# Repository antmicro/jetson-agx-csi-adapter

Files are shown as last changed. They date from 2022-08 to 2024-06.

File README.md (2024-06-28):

# Antmicro Jetson AGX CSI Adapter

Copyright (c) 2022-2024 [Antmicro](https://www.antmicro.com)



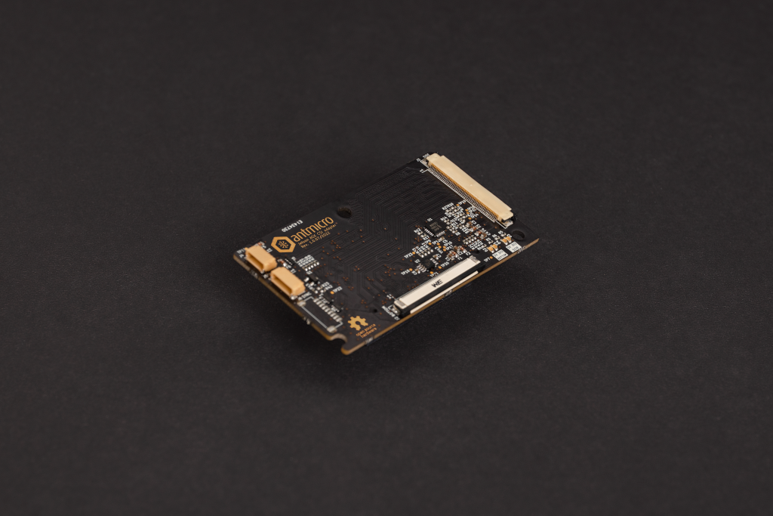
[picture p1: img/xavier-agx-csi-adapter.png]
Adapter Photo


## Overview
This project contains hardware design files for a CSI camera adapter designed to be used with Nvidia Jetson AGX platform devkits (Orin, Xavier).
It separates the camera module interface connector into two 50-pin flat cable connectors, which are compatible with a variety of video accessories developed by Antmicro.
 
## Project structure
The main directory contains KiCad PCB project files, a LICENSE, and a README.
The remaining files are stored in the following directories:

* `img` - contains graphics for this README
* `doc` - contains generated schematics and other documentation
* `assets` - contains visual assets for showcasing this design on [Open Hardware Portal](https://openhardware.antmicro.com)

## Key features
* Nvidia Camera Module Connector compatible with Jetson AGX Orin and Jetson Xavier AGX devkits,
* Two Antmicro CSI Connectors (2x 4-lane MIPI CSI-2 or 4x 4-lane MIPI CSI-2)
* I2C multiplexer for connecting multiple cameras to separate I2C interfaces
* On-board DC-DC converter to power the cameras
* Simple frame synchronization circuitry
* QWIIC connector for external sensors
* Liquid lens connector for I2C-controlled liquid lenses

The camera connectors are electrically compatible with several video accessories created by Antmicro, such as:
 
* [Antmicro - Alvium flexible CSI adapter](https://github.com/antmicro/alvium-flexible-csi-adapter)
* [OV9281 Dual Camera Board](https://github.com/antmicro/ov9281-camera-board)
* [SDI-MIPI bridge](https://github.com/antmicro/sdi-mipi-bridge)
* [HDMI-MIPI bridge](https://github.com/antmicro/hdmi-mipi-bridge)

## License
This project is published under the [Apache-2.0](LICENSE) license.

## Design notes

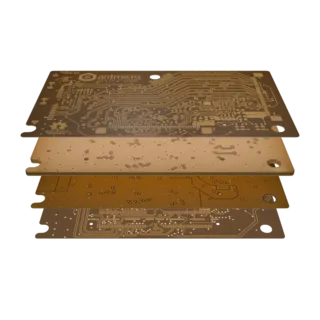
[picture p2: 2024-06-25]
assets/previews/layer1_thumbnail.webp

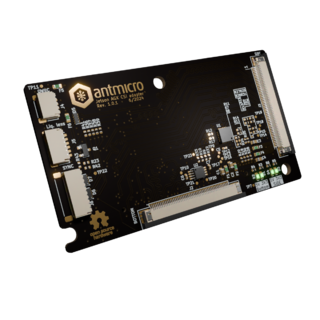
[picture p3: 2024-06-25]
assets/previews/leftT_thumbnail.png

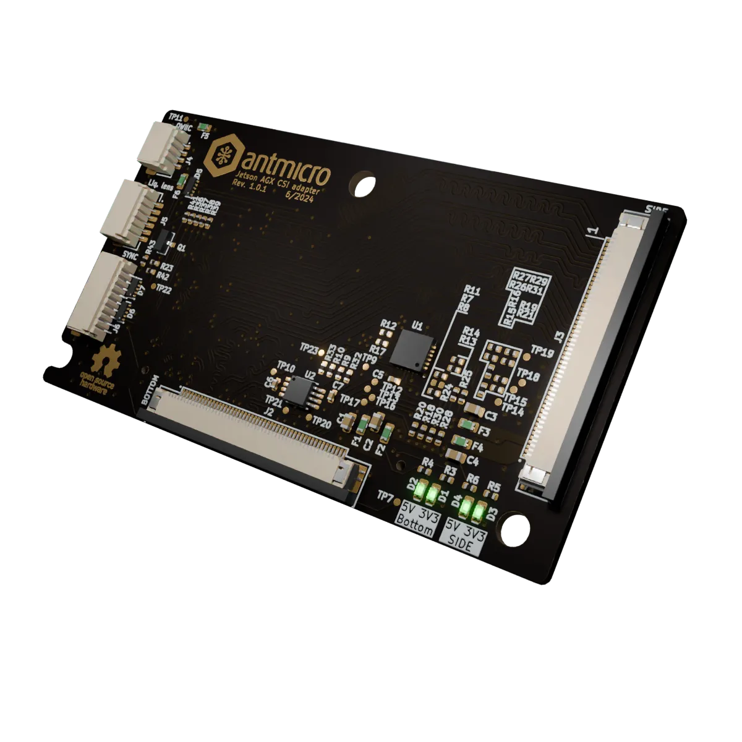
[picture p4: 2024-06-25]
assets/previews/rightT.webp

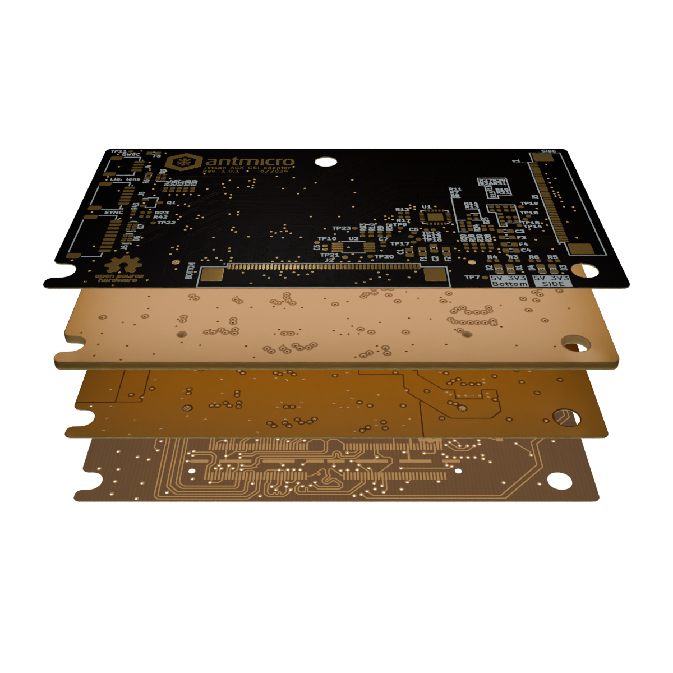
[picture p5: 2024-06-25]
assets/previews/stackup.png

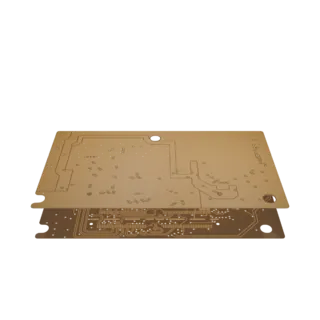
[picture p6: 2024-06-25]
assets/previews/layer3_thumbnail.webp

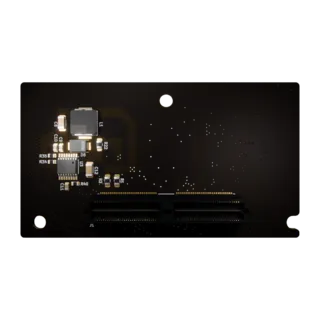
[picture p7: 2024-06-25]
assets/previews/orthoB_thumbnail.webp

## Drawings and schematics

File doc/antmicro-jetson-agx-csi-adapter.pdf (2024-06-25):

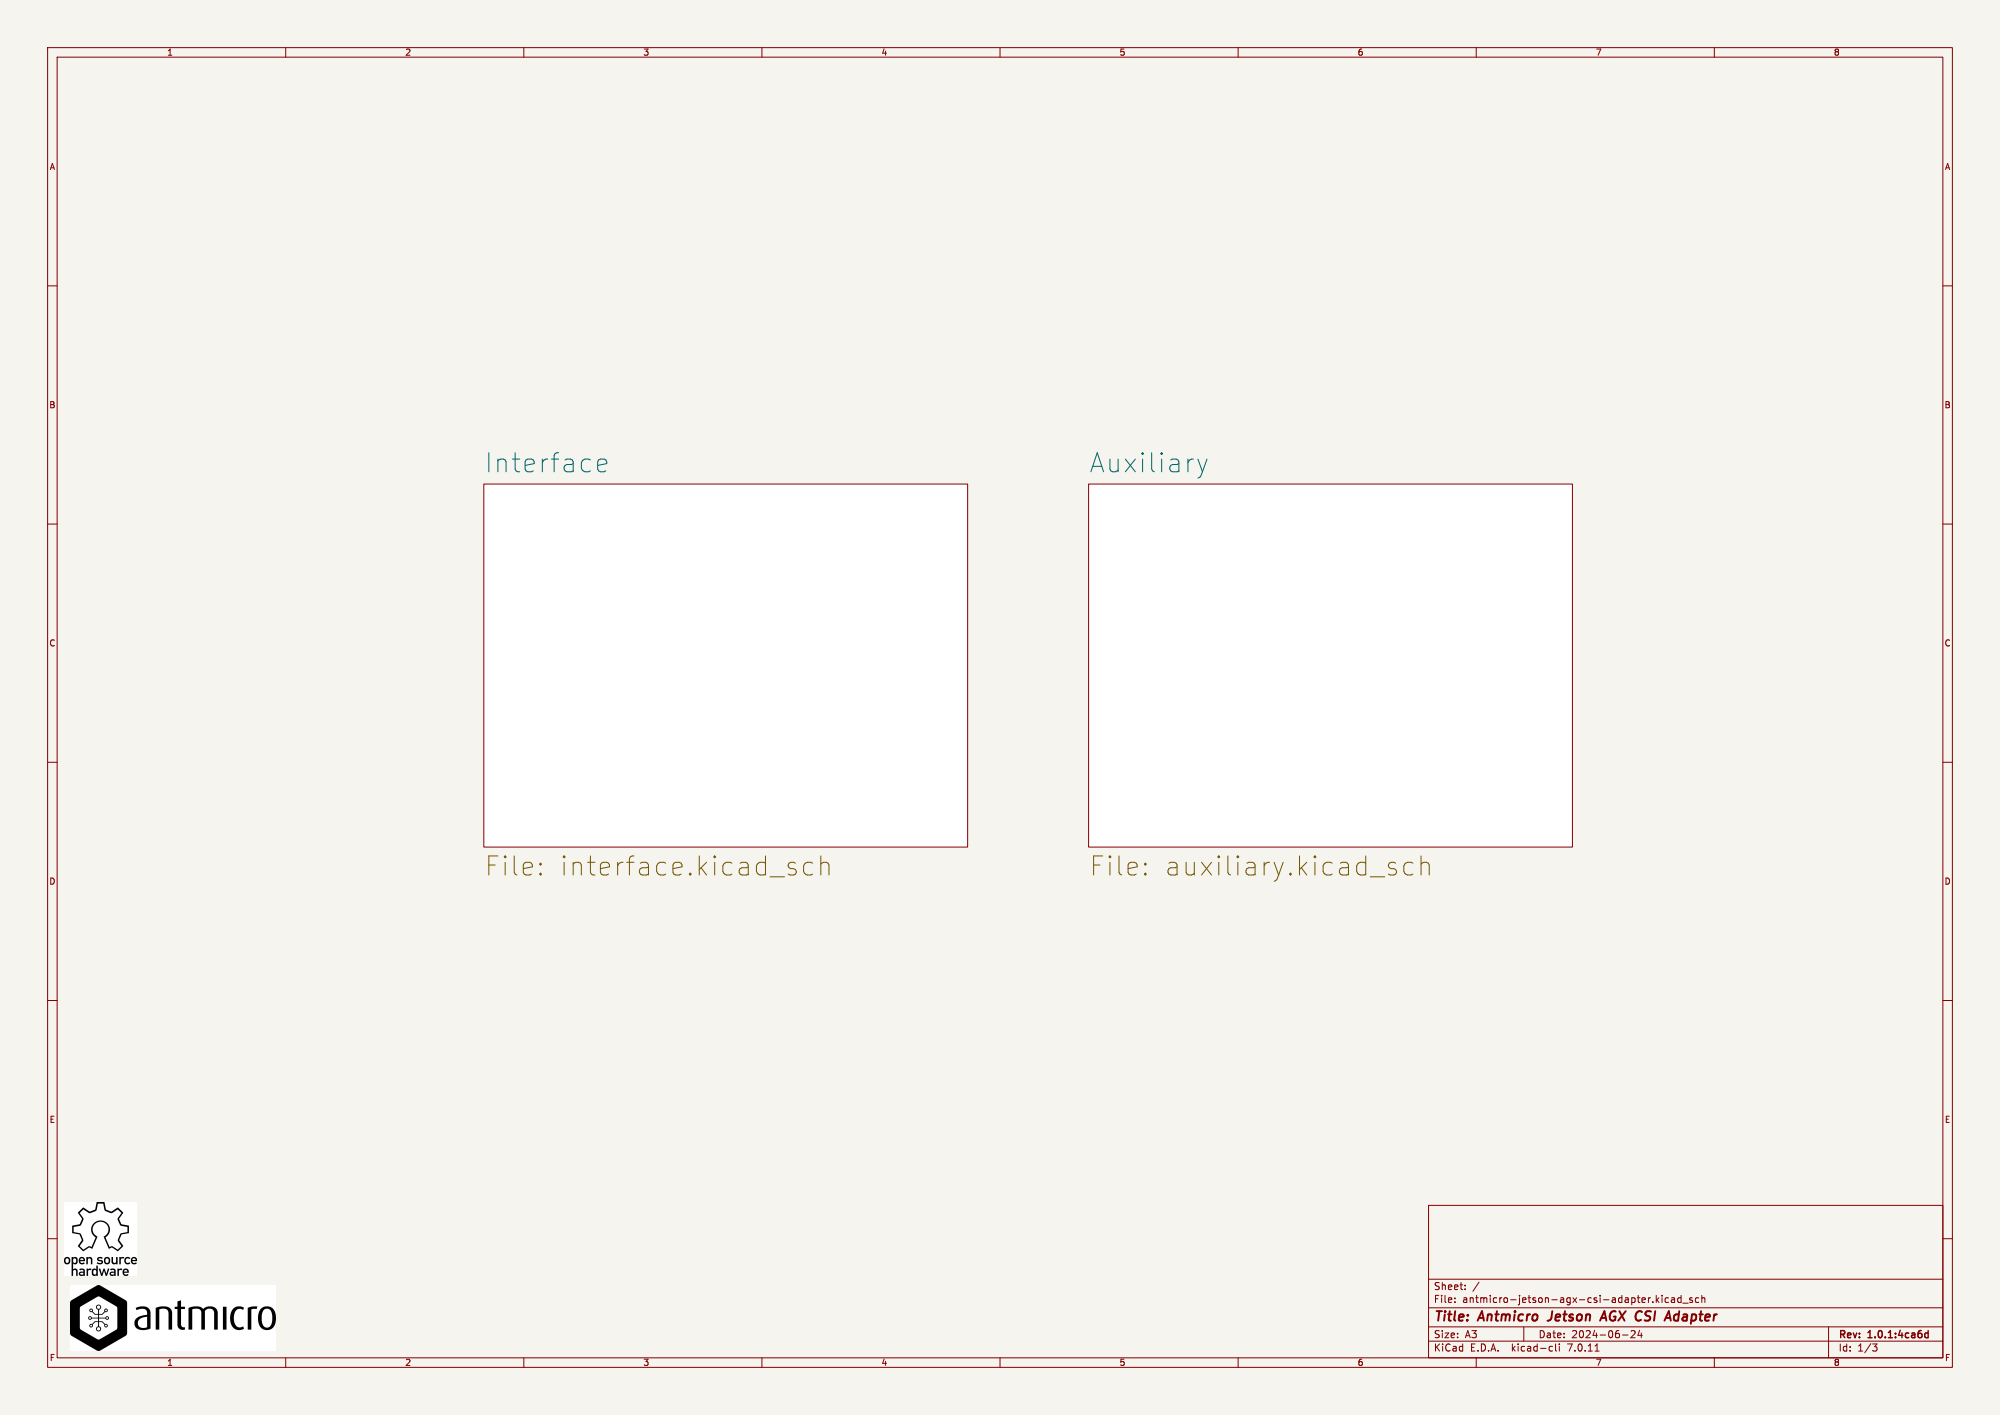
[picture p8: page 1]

Id: 1/3 Title: Antmicro Jetson AGX CSI Adapter File: antmicro-jetson-agx-csi-adapter.kicad_sch Sheet: /

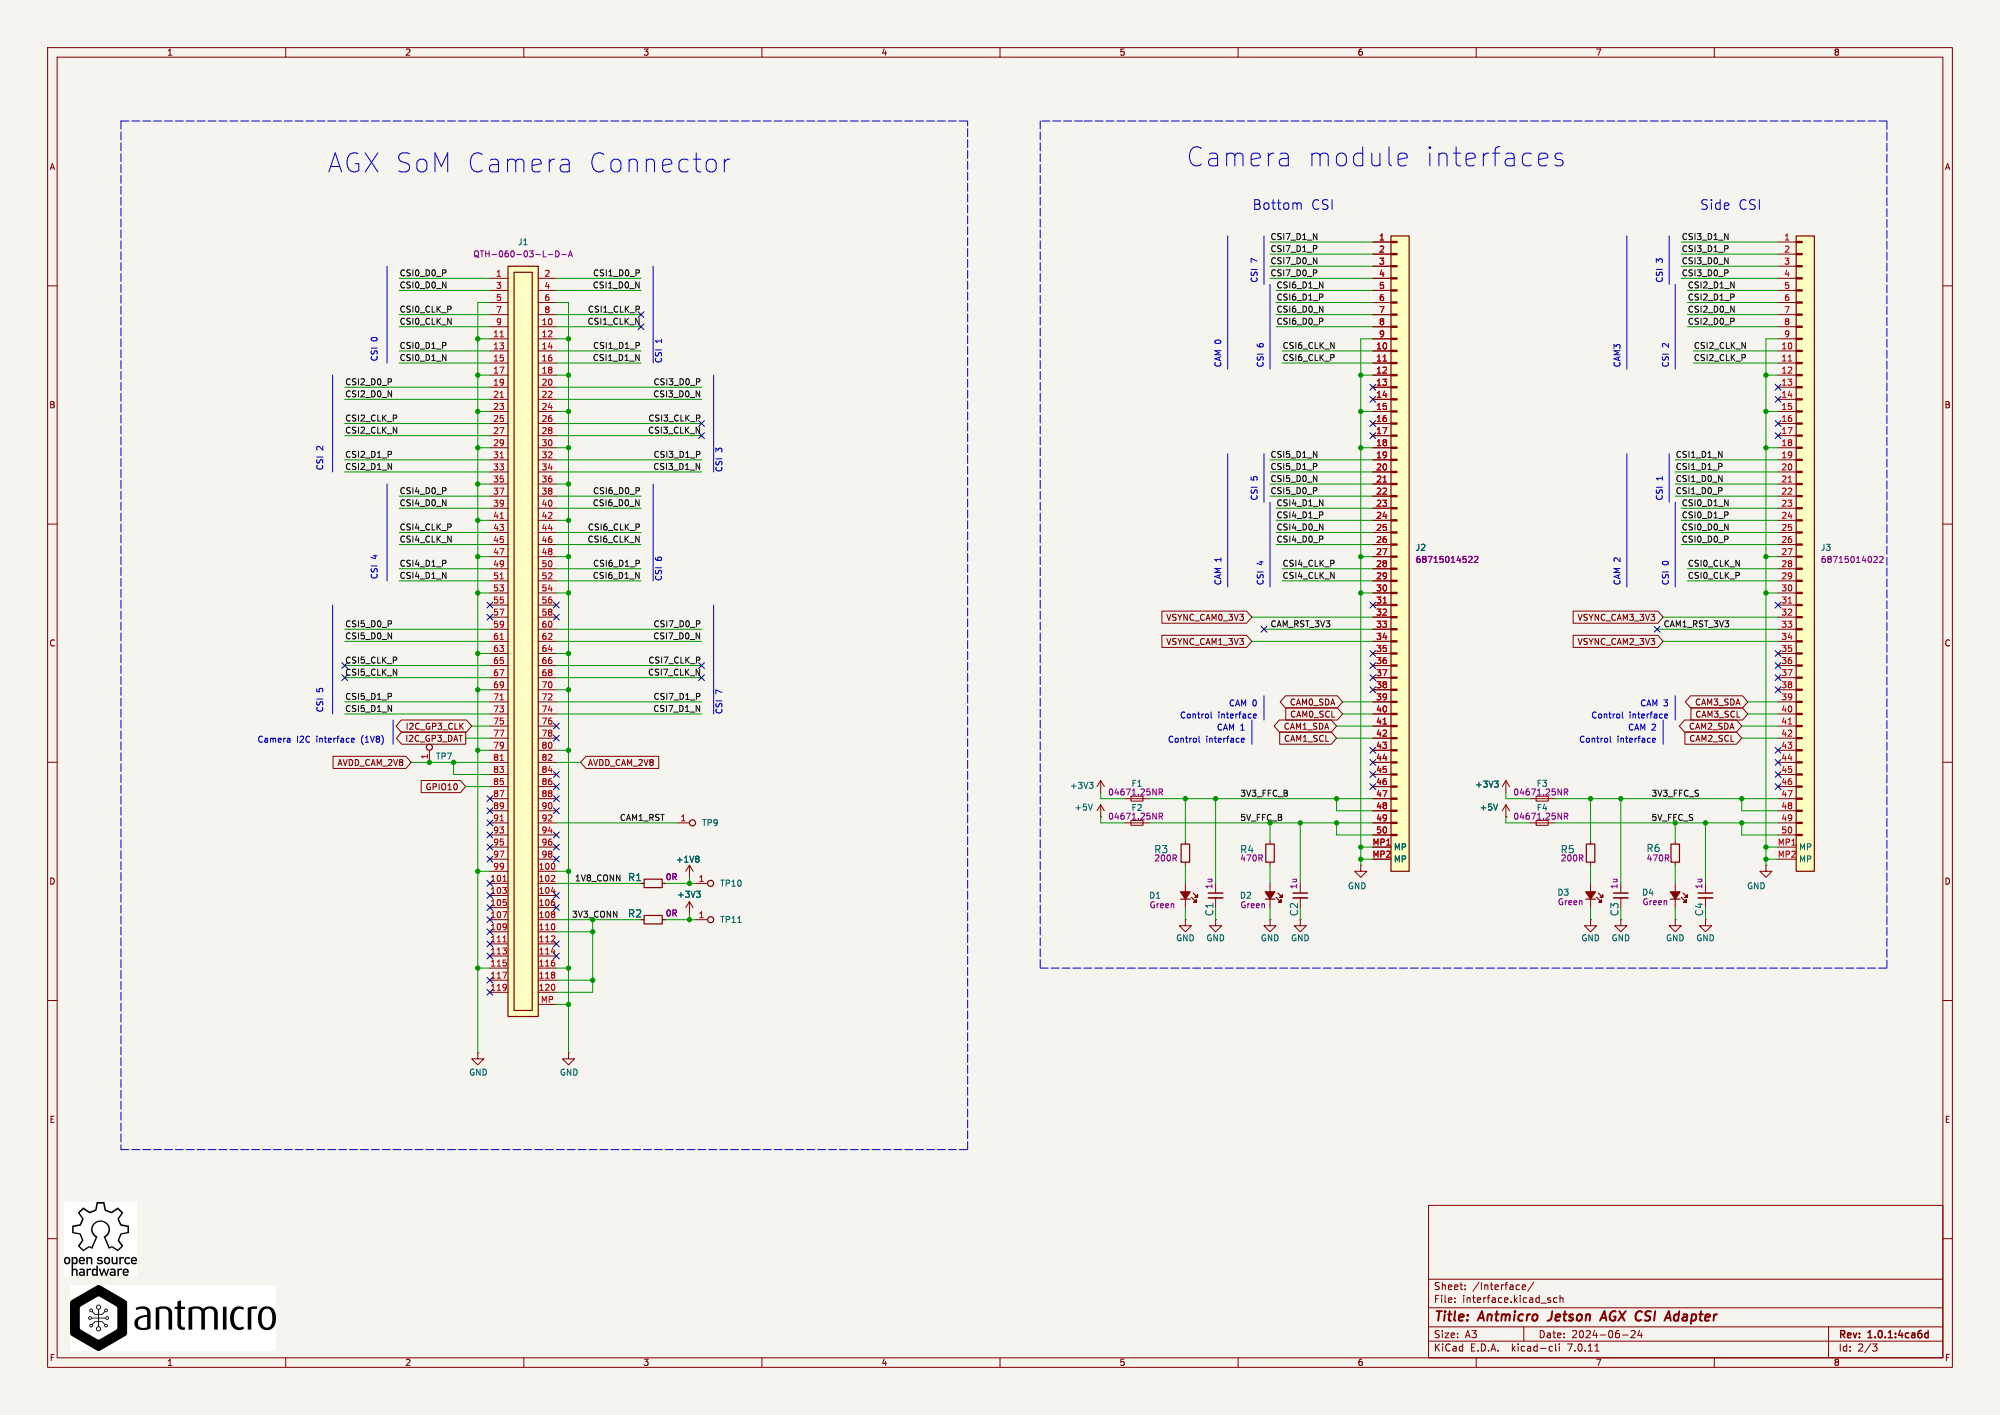
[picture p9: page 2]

Id: 2/3 Title: Antmicro Jetson AGX CSI Adapter File: interface.kicad_sch Sheet: /Interface/

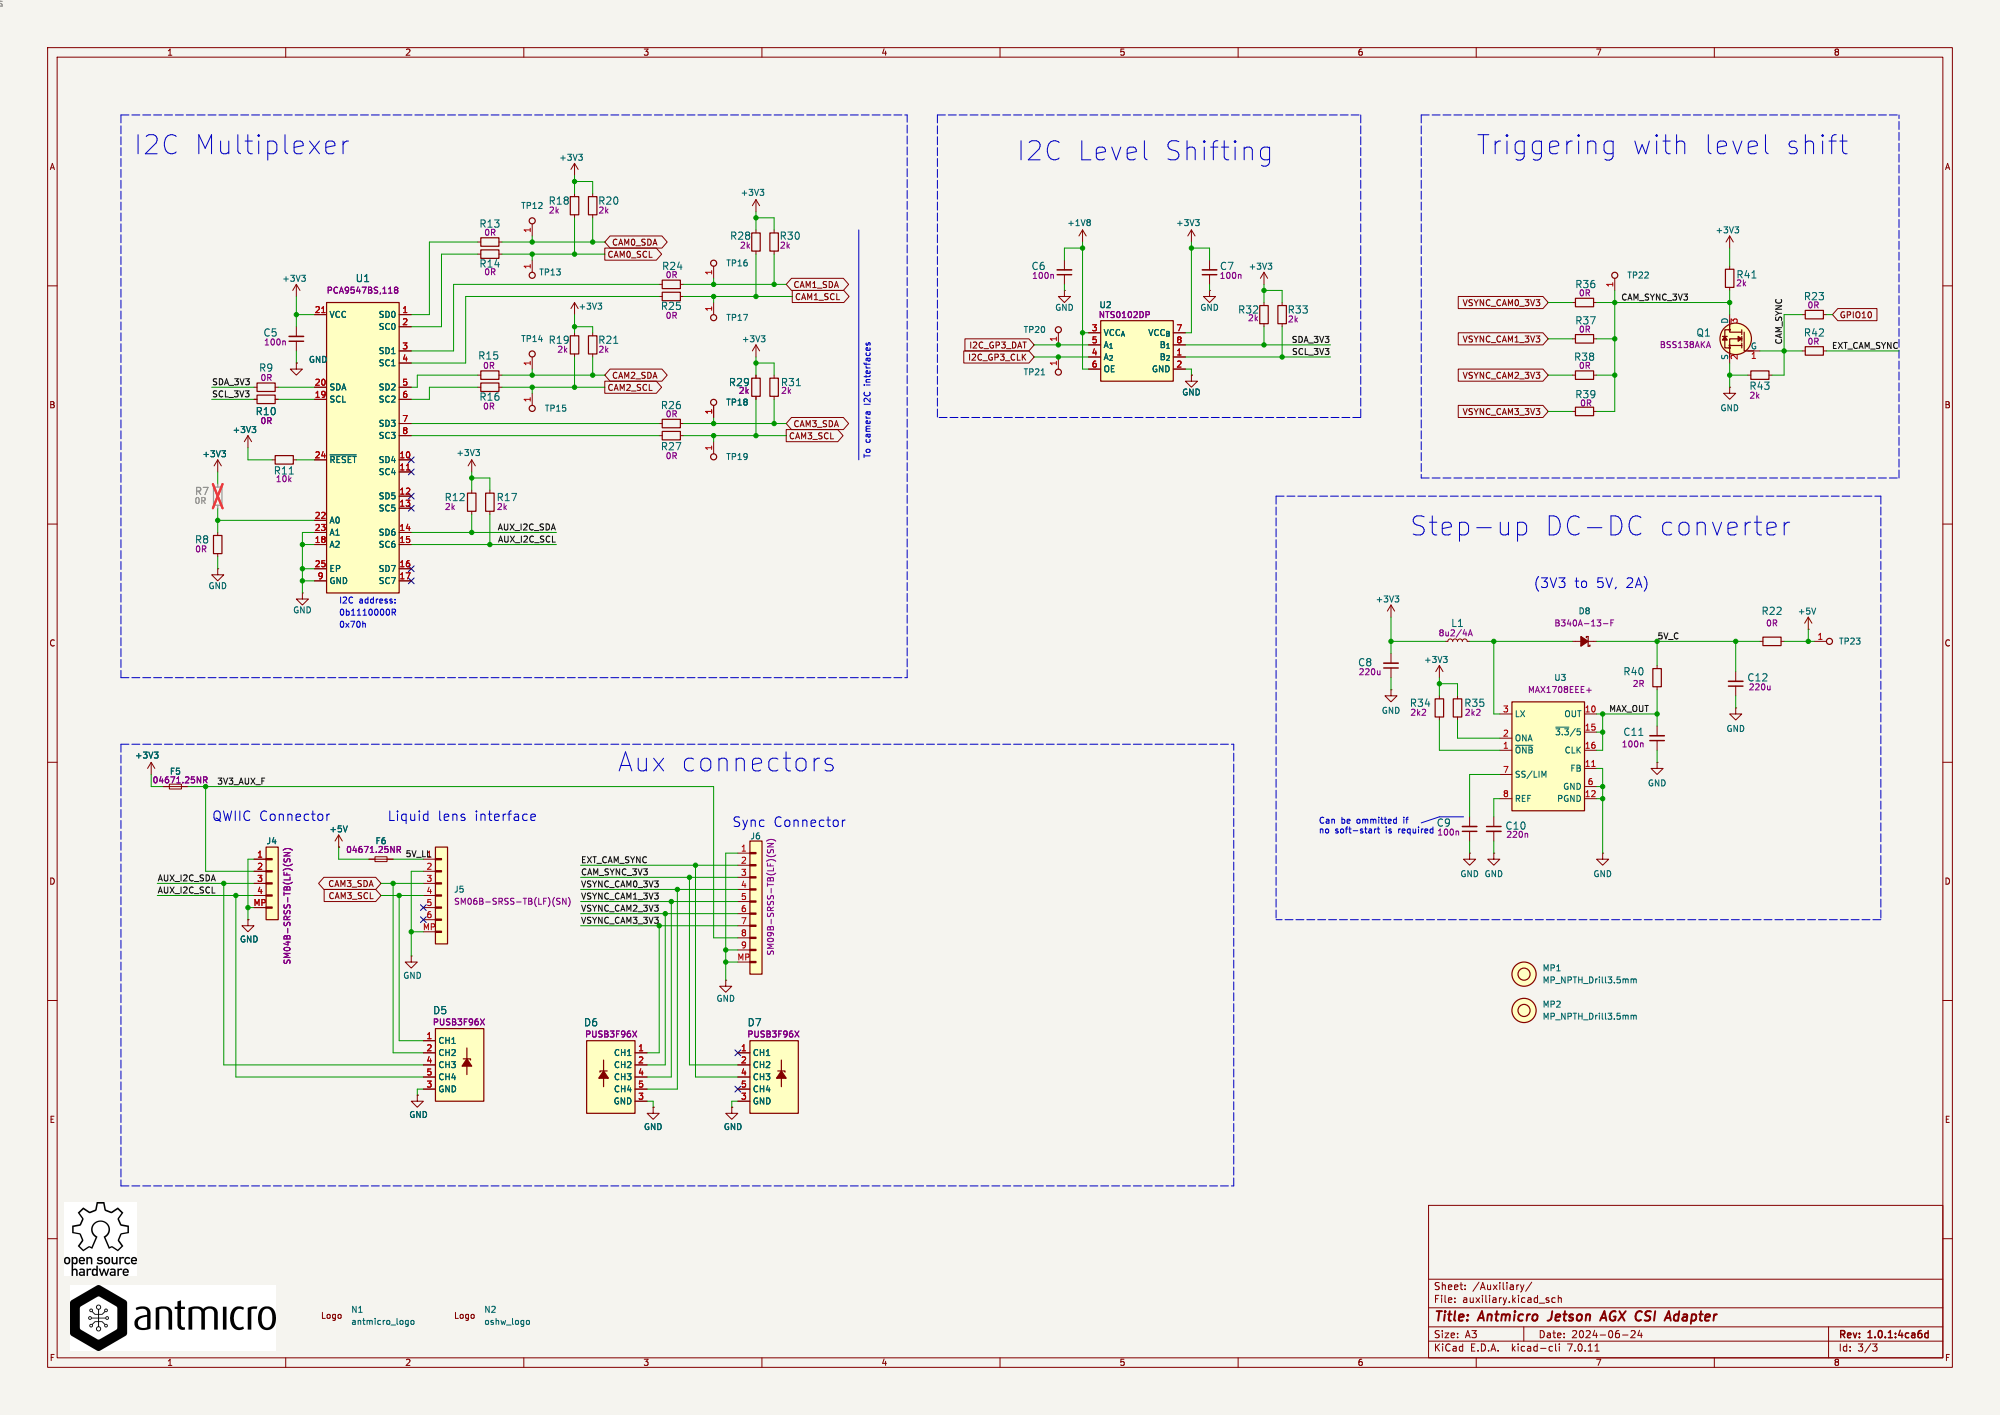
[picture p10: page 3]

(3V3 to 5V, 2A) To camera I2C interfaces

J4 SM04B-SRSS-TB(LF)(SN)
4MP GND

Id: 3/3 Title: Antmicro Jetson AGX CSI Adapter File: auxiliary.kicad_sch Sheet: /Auxiliary/

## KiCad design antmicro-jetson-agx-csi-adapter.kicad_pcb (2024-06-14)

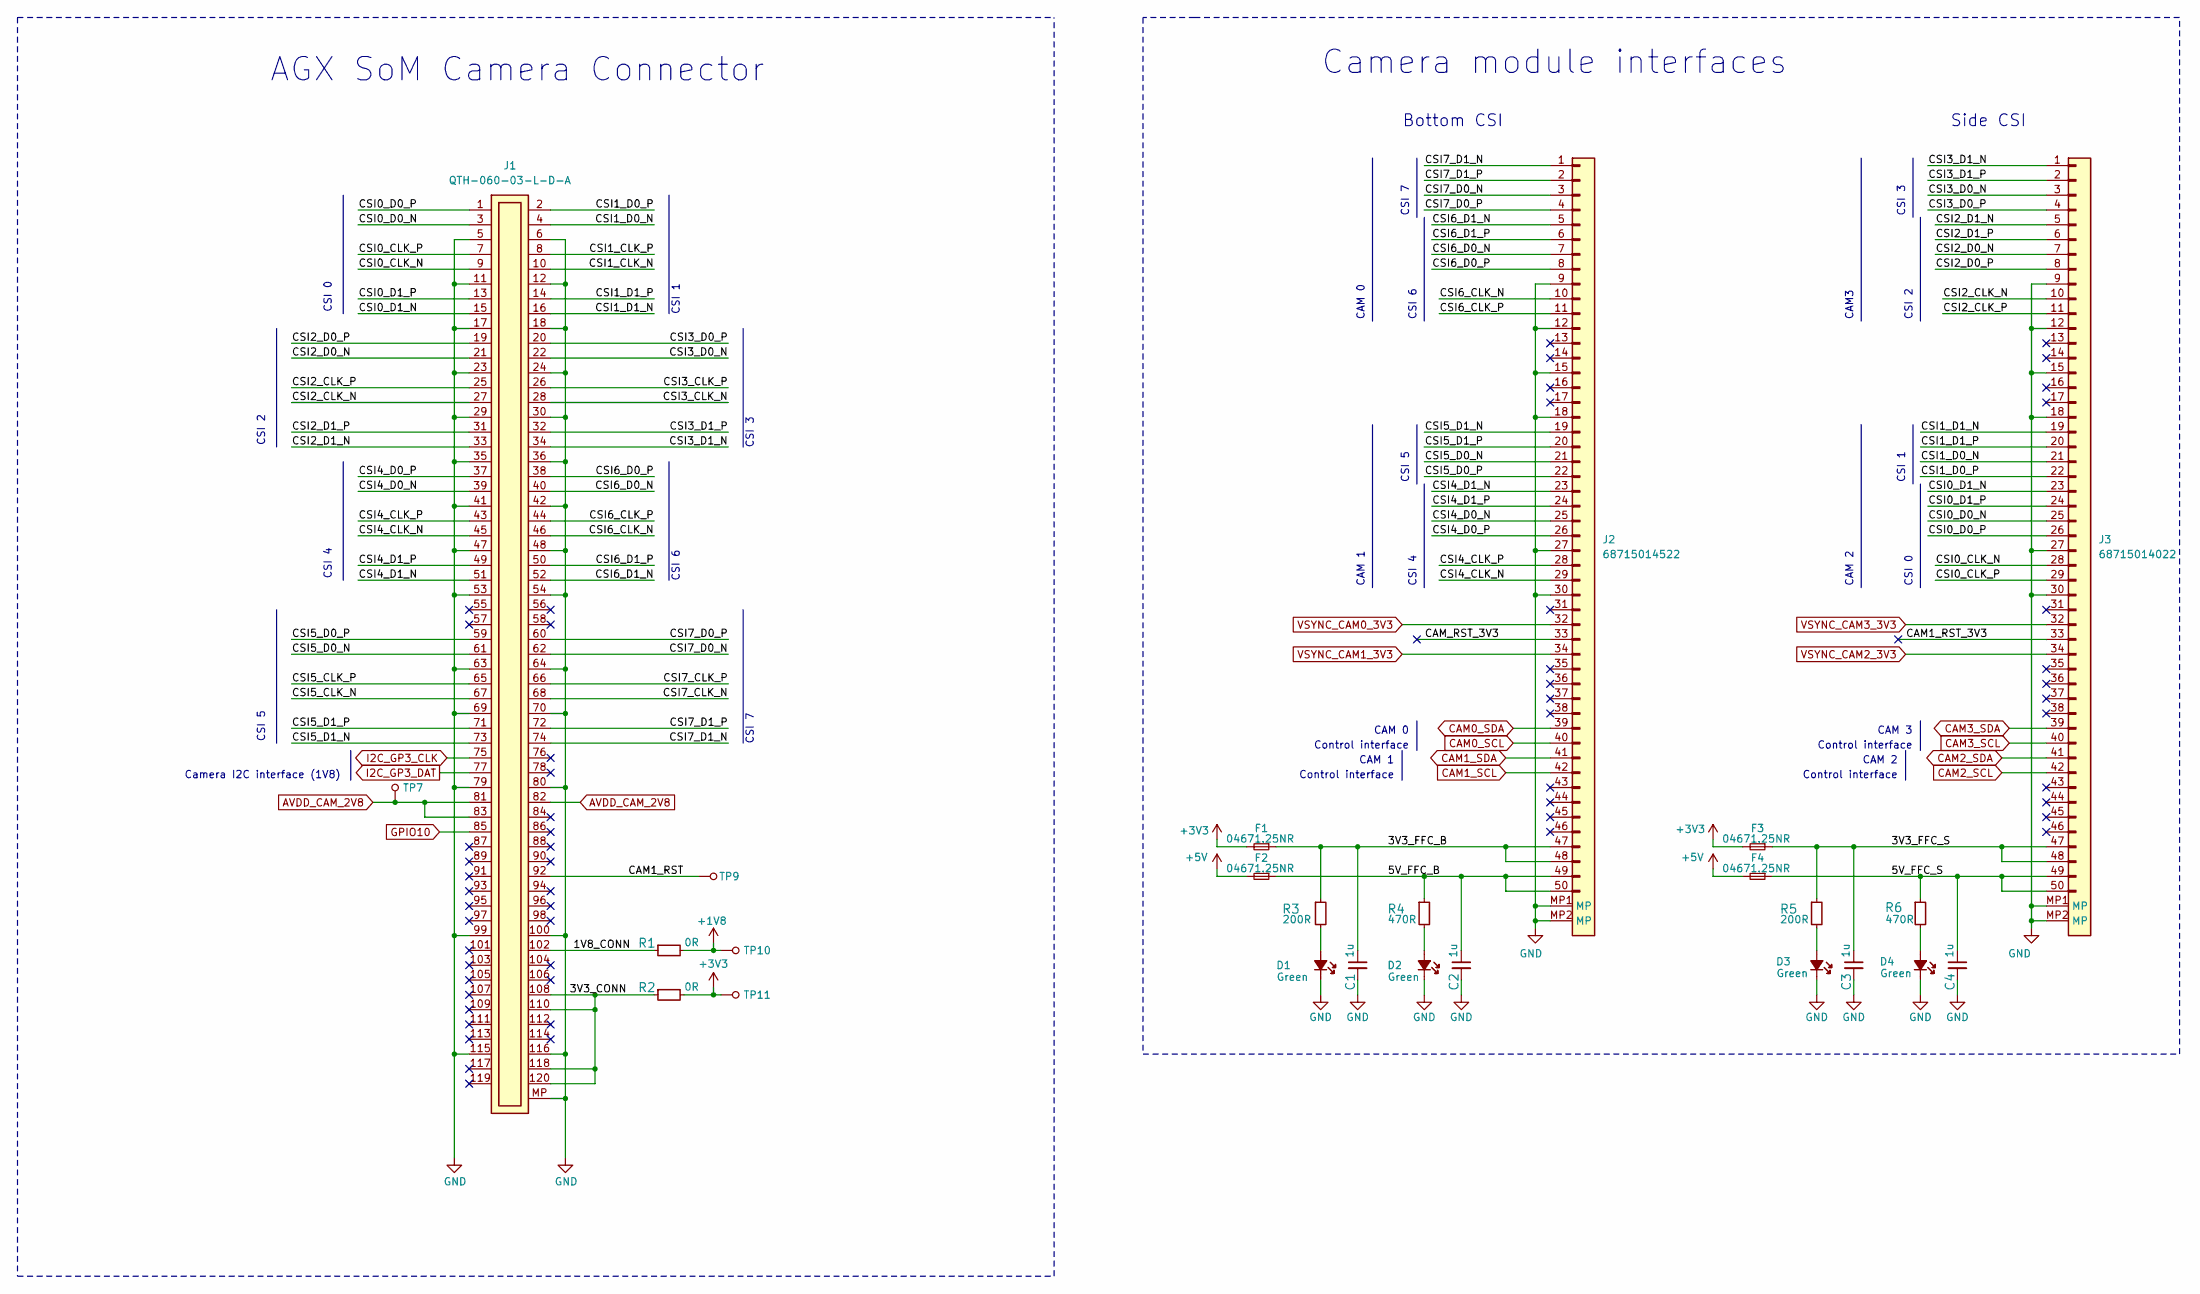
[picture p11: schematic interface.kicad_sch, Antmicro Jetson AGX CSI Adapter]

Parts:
C1, C2, C3, C4: C_1u_0603; C_0603_1608Metric; MPN 0603YD105KAT2A
D1, D2, D3, D4: LED_G_0603_LTST-C190GKT; LED_0603_1608Metric_G; MPN LTST-C190GKT
F1, F2, F3, F4: F_1.25A_0603; F_0603_1608Metric; MPN 04671.25NR
J1: Plug_Samtec_QTH_2x60_QTH-060-03-L-D-A; Conn_Plug_Samtec_QTH_2x60_QTH-060-03-L-D-A; MPN QTH-060-03-L-D-A
J2: Conn_FFC_WE_68715014522; Conn_FFC_WE_68715014x22; MPN 68715014522
J3: Conn_FFC_WE_68715014022_CUSTOM_FLIPPED; Conn_FFC_WE_68715014x22_CUSTOM_FLIPPED; MPN 68715014022
R1, R2: R_0R_0805; R_0805_2012Metric; MPN CRCW08050000Z0EA
R3, R5: R_200R_0402; R_0402_1005Metric; Tolerance 1%; MPN CR0402-FX-2000GLF
R4, R6: R_470R_0402; R_0402_1005Metric; Tolerance 1%; MPN CR0402-FX-4700GLF
TP7, TP9, TP10, TP11: TP_SMD_0_75MM; Testpoint_smd_0_75mm

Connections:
+1V8: R1.2, TP10.1; also elsewhere on the board
+3V3: F1.2, F3.2, R2.2, TP11.1; also elsewhere on the board
+5V: F2.2, F4.2; also elsewhere on the board
/Interface/1V8_CONN: J1.102, R1.1
/Interface/3V3_CONN: J1.108, J1.110, J1.118, J1.120, R2.1
/Interface/3V3_FFC_B: C1.1, F1.1, J2.47, J2.48, R3.1
/Interface/3V3_FFC_S: C3.1, F3.1, J3.47, J3.48, R5.1
/Interface/5V_FFC_B: C2.1, F2.1, J2.49, J2.50, R4.1
/Interface/5V_FFC_S: C4.1, F4.1, J3.49, J3.50, R6.1
/Interface/CAM1_RST: J1.92, TP9.1
/Interface/CAM1_RST_3V3: J3.33
/Interface/CAM_RST_3V3: J2.33
/Interface/CSI0_CLK_N: J1.9, J3.28
/Interface/CSI0_CLK_P: J1.7, J3.29
/Interface/CSI0_D0_N: J1.3, J3.25
/Interface/CSI0_D0_P: J1.1, J3.26
/Interface/CSI0_D1_N: J1.15, J3.23
/Interface/CSI0_D1_P: J1.13, J3.24
/Interface/CSI1_CLK_N: J1.10
/Interface/CSI1_CLK_P: J1.8
/Interface/CSI1_D0_N: J1.4, J3.21
/Interface/CSI1_D0_P: J1.2, J3.22
/Interface/CSI1_D1_N: J1.16, J3.19
/Interface/CSI1_D1_P: J1.14, J3.20
/Interface/CSI2_CLK_N: J1.27, J3.10
/Interface/CSI2_CLK_P: J1.25, J3.11
/Interface/CSI2_D0_N: J1.21, J3.7
/Interface/CSI2_D0_P: J1.19, J3.8
/Interface/CSI2_D1_N: J1.33, J3.5
/Interface/CSI2_D1_P: J1.31, J3.6
/Interface/CSI3_CLK_N: J1.28
/Interface/CSI3_CLK_P: J1.26
/Interface/CSI3_D0_N: J1.22, J3.3
/Interface/CSI3_D0_P: J1.20, J3.4
/Interface/CSI3_D1_N: J1.34, J3.1
/Interface/CSI3_D1_P: J1.32, J3.2
/Interface/CSI4_CLK_N: J1.45, J2.29
/Interface/CSI4_CLK_P: J1.43, J2.28
/Interface/CSI4_D0_N: J1.39, J2.25
/Interface/CSI4_D0_P: J1.37, J2.26
/Interface/CSI4_D1_N: J1.51, J2.23
/Interface/CSI4_D1_P: J1.49, J2.24
/Interface/CSI5_CLK_N: J1.67
/Interface/CSI5_CLK_P: J1.65
/Interface/CSI5_D0_N: J1.61, J2.21
/Interface/CSI5_D0_P: J1.59, J2.22
/Interface/CSI5_D1_N: J1.73, J2.19
/Interface/CSI5_D1_P: J1.71, J2.20
/Interface/CSI6_CLK_N: J1.46, J2.10
/Interface/CSI6_CLK_P: J1.44, J2.11
/Interface/CSI6_D0_N: J1.40, J2.7
/Interface/CSI6_D0_P: J1.38, J2.8
/Interface/CSI6_D1_N: J1.52, J2.5
/Interface/CSI6_D1_P: J1.50, J2.6
/Interface/CSI7_CLK_N: J1.68
/Interface/CSI7_CLK_P: J1.66
/Interface/CSI7_D0_N: J1.62, J2.3
/Interface/CSI7_D0_P: J1.60, J2.4
/Interface/CSI7_D1_N: J1.74, J2.1
/Interface/CSI7_D1_P: J1.72, J2.2
AVDD_CAM_2V8: J1.81, J1.82, J1.83, TP7.1
CAM0_SCL: J2.40; also elsewhere on the board
CAM0_SDA: J2.39; also elsewhere on the board
CAM1_SCL: J2.42; also elsewhere on the board
CAM1_SDA: J2.41; also elsewhere on the board
CAM2_SCL: J3.42; also elsewhere on the board
CAM2_SDA: J3.41; also elsewhere on the board
CAM3_SCL: J3.40; also elsewhere on the board
CAM3_SDA: J3.39; also elsewhere on the board
GND: C1.2, C2.2, C3.2, C4.2, D1.1 (C), D2.1 (C), D3.1 (C), D4.1 (C), J1.5, J1.6, J1.11, J1.12, J1.17, J1.18, J1.23, J1.24, J1.29, J1.30, J1.35, J1.36, J1.41, J1.42, J1.47, J1.48, J1.53, J1.54, J1.63, J1.64, J1.69, J1.70, J1.79, J1.80, J1.99, J1.100, J1.115, J1.116, J1.MP, J2.9, J2.12, J2.15, J2.18, J2.27, J2.30, J2.MP1 (MP), J2.MP2 (MP), J3.9, J3.12, J3.15, J3.18, J3.27, J3.30, J3.MP1 (MP), J3.MP2 (MP); also elsewhere on the board
GPIO10: J1.85; also elsewhere on the board
I2C_GP3_CLK: J1.75; also elsewhere on the board
I2C_GP3_DAT: J1.77; also elsewhere on the board
unnamed: D1.2 (A), R3.2
unnamed: D2.2 (A), R4.2
unnamed: D3.2 (A), R5.2
unnamed: D4.2 (A), R6.2
VSYNC_CAM0_3V3: J2.32; also elsewhere on the board
VSYNC_CAM1_3V3: J2.34; also elsewhere on the board
VSYNC_CAM2_3V3: J3.34; also elsewhere on the board
VSYNC_CAM3_3V3: J3.32; also elsewhere on the board

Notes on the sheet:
CSI 1
AGX SoM Camera Connector
CAM 0
CAM 2
CSI 4
Control interface
Camera module interfaces
CAM 1
CSI 6
CSI 7
CSI 0
CSI 5
Bottom CSI
CSI 3
CSI 2
CAM 3
Side CSI
CAM3
Camera I2C interface (1V8)

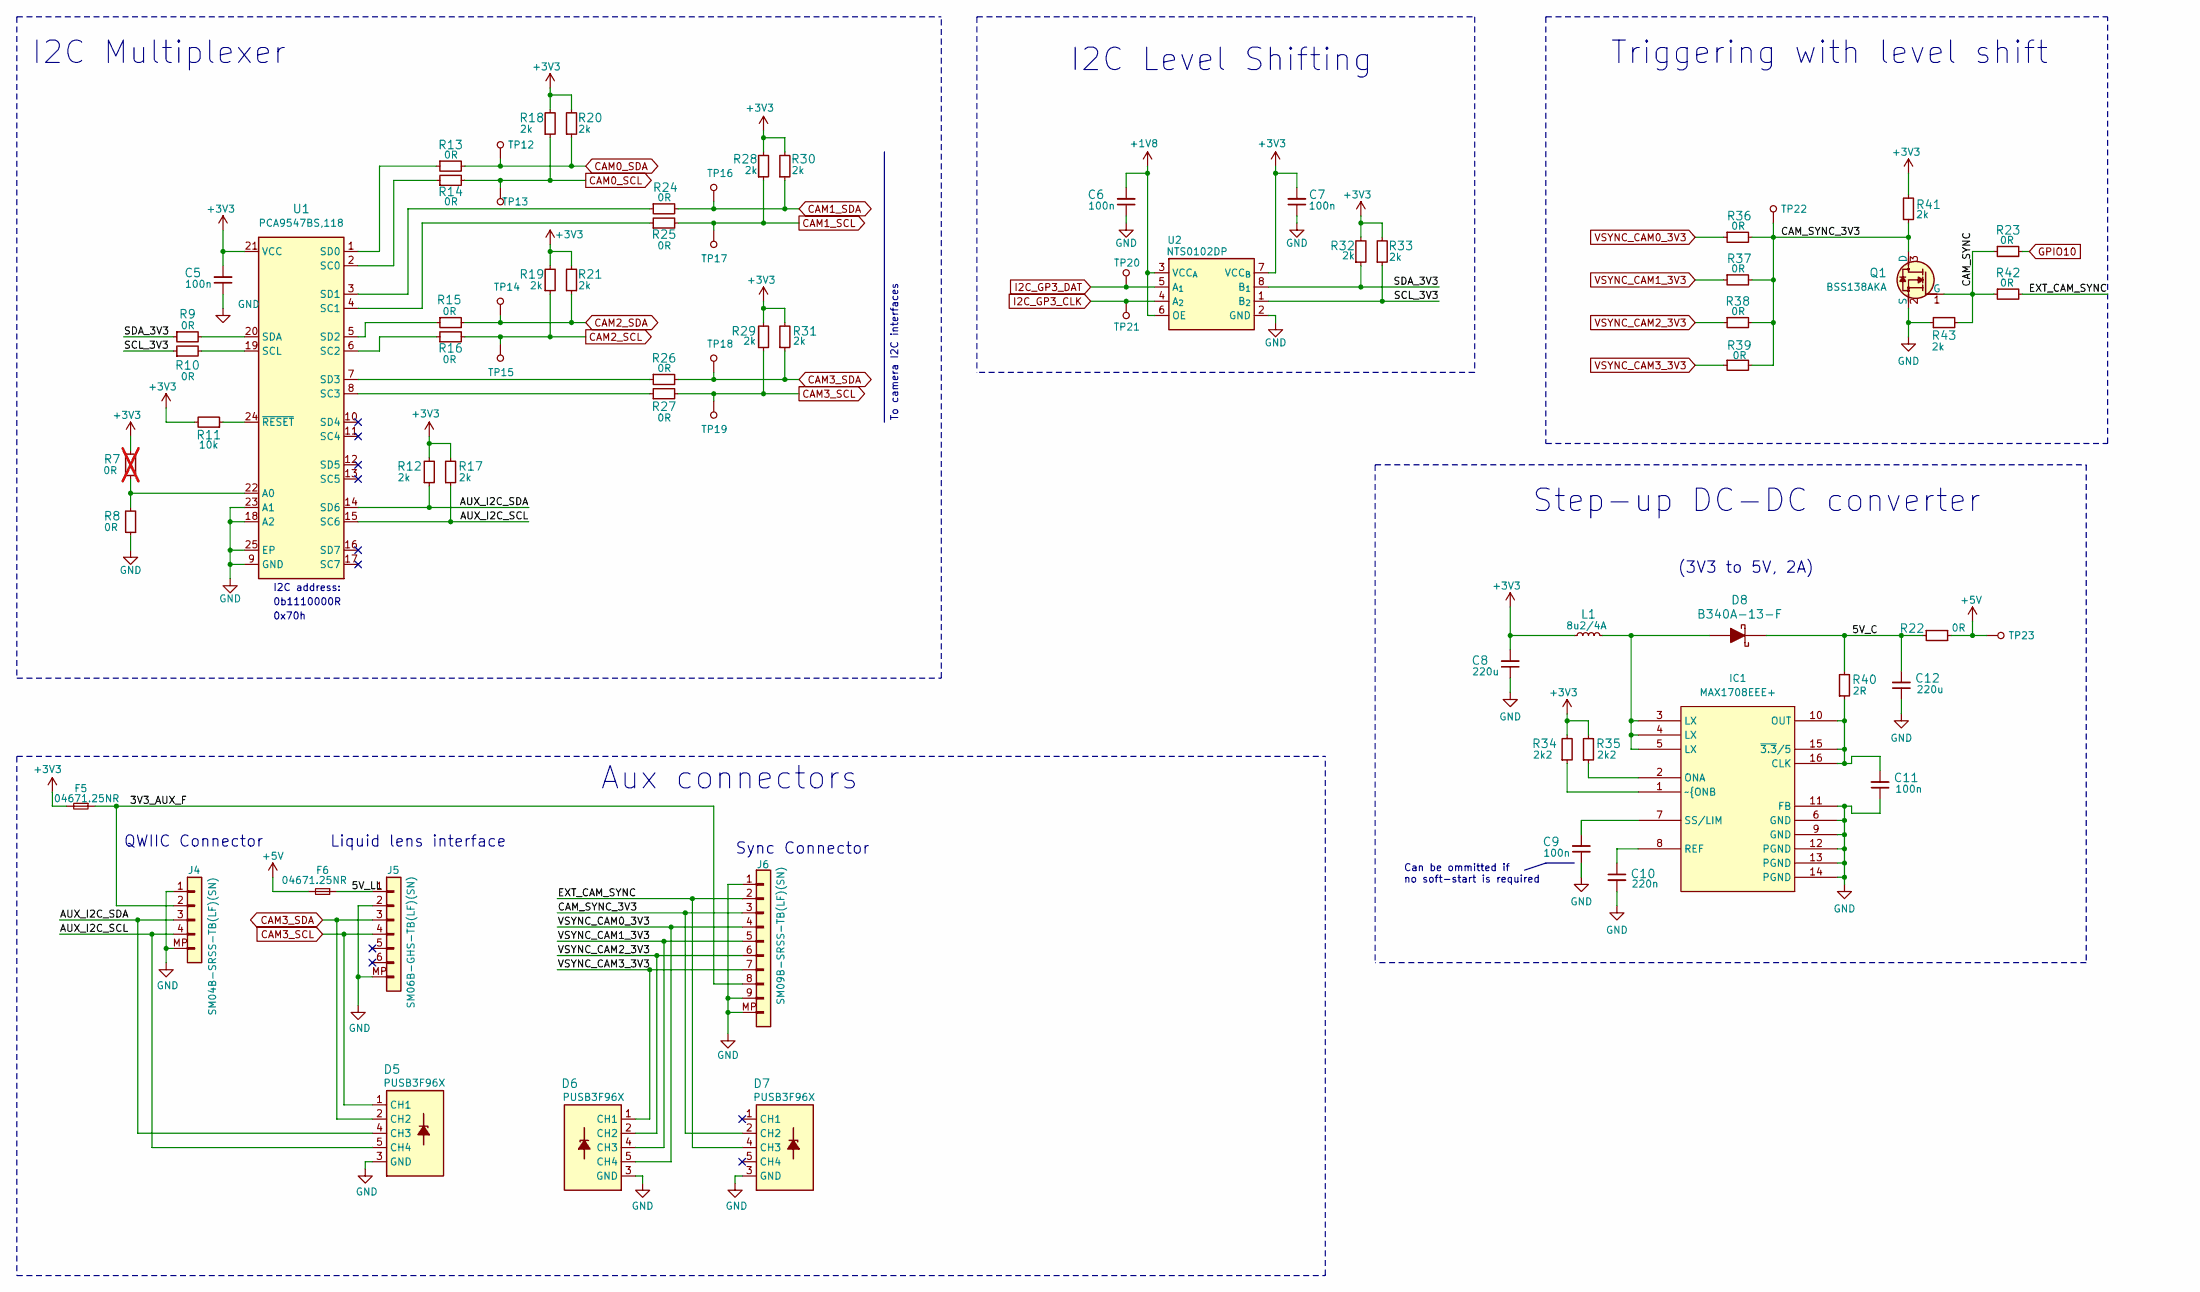
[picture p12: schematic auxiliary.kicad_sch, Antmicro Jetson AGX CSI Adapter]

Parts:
C5, C6, C7: C_100n_0402; C_0402_1005Metric; Voltage 50V; MPN GRM155R61H104KE14D
C8, C12: C_220u_1206_6V3; C_1206_3216Metric; MPN GRM31CR60J227ME11L
C9, C11: C_100n_0603; C_0603_1608Metric; MPN 0603YC104KAZ2A
C10: C_220n_0603; C_0603_1608Metric; MPN 0603B224K100CT
D5, D6, D7: PUSB3F96X_PASS; Nexperia_DFN-10_2.5x1mm_P0.5mm; MPN PUSB3F96X
D8: B340A-13-F; DO-214AC; MPN B340A-13-F
F5, F6: F_1.25A_0603; F_0603_1608Metric; MPN 04671.25NR
IC1: MAX1708EEE+; QSOP-16_3.9x4.9mm_P0.635mm; MPN MAX1708EEE+
J4: JST_SH_1x4_SM04B-SRSS-TB-LF-SN; Conn_JST_SH_1x4_SM04B-SRSS-TB-LF-SN; MPN SM04B-SRSS-TB(LF)(SN)
J5: JST_GH_1x6_SM06B-GHS-TB-LF-SN; Conn_JST_GH_1x6_SM06B-GHS-TB-LF-SN; MPN SM06B-GHS-TB(LF)(SN)
J6: JST_SH_1x9_SM09B-SRSS-TB-LF-SN; Conn_JST_SH_1x9_SM09B-SRSS-TB-LF-SN; MPN SM09B-SRSS-TB(LF)(SN)
L1: L_8u2_4A_2525; L_2525_6363Metric; MPN IHLP2525CZER8R2M01
Q1: BSS138AKA; SOT-23-3; MPN BSS138AKA
R7: R_0R_0402; R_0402_1005Metric; MPN ERJ2GE0R00X; not fitted
R8, R9, R10, R13, R14, R15, R16, R23, R24, R25, R26, R27, R36, R37, R38, R39, R42: R_0R_0402; R_0402_1005Metric; MPN ERJ2GE0R00X
R11: R_10k_0402; R_0402_1005Metric; Tolerance 1%; MPN CR0402-FX-1002GLF
R12, R17, R18, R19, R20, R21, R28, R29, R30, R31, R32, R33, R41, R43: R_2k_0402; R_0402_1005Metric; Tolerance 1%; MPN CR0402-FX-2001GLF
R22: R_0R_0805; R_0805_2012Metric; MPN CRCW08050000Z0EA
R34, R35: R_2k2_0603; R_0603_1608Metric; Tolerance 1%; MPN CR0603-FX-2201ELF
R40: R_2R_0603; R_0603_1608Metric; Tolerance 1%; MPN CR0603-FX-2R00ELF
TP12, TP13, TP14, TP15, TP16, TP17, TP18, TP19, TP20, TP21, TP22, TP23: TP_SMD_0_75MM; Testpoint_smd_0_75mm
U1: PCA9547_VQFN; VQFN-24-1EP_3.8x3.8x1.0mm_P0.5mm; MPN PCA9547BS,118
U2: NTS0102_TSSOP; TSSOP-8_3x3mm_P0.65mm; MPN NTS0102DP

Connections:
+1V8: C6.2, U2.3 (VCC_{A}), U2.6 (OE); also elsewhere on the board
+3V3: C5.2, C7.2, C8.2, F5.2, L1.1, R7.2, R11.2, R12.2, R17.2, R18.2, R19.2, R20.2, R21.2, R28.2, R29.2, R30.2, R31.2, R32.2, R33.2, R34.2, R35.2, R41.2, U1.21 (VCC), U2.7 (VCC_{B}); also elsewhere on the board
+5V: F6.2, R22.2, TP23.1; also elsewhere on the board
/Auxiliary/3V3_AUX_F: F5.1, J4.2, J6.8
/Auxiliary/5V_C: C12.2, D8.K, R22.1, R40.2
/Auxiliary/5V_LL: F6.1, J5.1
/Auxiliary/AUX_I2C_SCL: D5.5 (CH4), D5.6 (CH4), J4.4, R17.1, U1.15 (SC6)
/Auxiliary/AUX_I2C_SDA: D5.4 (CH3), D5.7 (CH3), J4.3, R12.1, U1.14 (SD6)
/Auxiliary/CAM_SYNC: Q1.1 (G), R23.1, R42.1, R43.2
/Auxiliary/CAM_SYNC_3V3: D7.2 (CH2), D7.9 (CH2), J6.3, Q1.3 (D), R36.2, R37.2, R38.2, R39.2, R41.1, TP22.1
/Auxiliary/EXT_CAM_SYNC: D7.4 (CH3), D7.7 (CH3), J6.2, R42.2
/Auxiliary/SCL_3V3: R10.1, R33.1, U2.1 (B_{2})
/Auxiliary/SDA_3V3: R9.1, R32.1, U2.8 (B_{1})
CAM0_SCL: R14.2, R18.1, TP13.1; also elsewhere on the board
CAM0_SDA: R13.2, R20.1, TP12.1; also elsewhere on the board
CAM1_SCL: R25.2, R28.1, TP17.1; also elsewhere on the board
CAM1_SDA: R24.2, R30.1, TP16.1; also elsewhere on the board
CAM2_SCL: R16.2, R19.1, TP15.1; also elsewhere on the board
CAM2_SDA: R15.2, R21.1, TP14.1; also elsewhere on the board
CAM3_SCL: D5.1 (CH1), D5.10 (CH1), J5.4, R27.2, R29.1, TP19.1; also elsewhere on the board
CAM3_SDA: D5.2 (CH2), D5.9 (CH2), J5.3, R26.2, R31.1, TP18.1; also elsewhere on the board
GND: C5.1, C6.1, C7.1, C8.1, C9.1, C10.2, C11.1, C12.1, D5.3 (GND), D5.8 (GND), D6.3 (GND), D6.8 (GND), D7.3 (GND), D7.8 (GND), IC1.6 (GND), IC1.9 (GND), IC1.11 (FB), IC1.12 (PGND), IC1.13 (PGND), IC1.14 (PGND), J4.1, J4.MP, J5.2, J5.MP, J6.1, J6.9, J6.MP, Q1.2 (S), R8.1, R43.1, U1.9 (GND), U1.18 (A2), U1.23 (A1), U1.25 (EP), U2.2 (GND); also elsewhere on the board
GPIO10: R23.2; also elsewhere on the board
I2C_GP3_CLK: TP21.1, U2.4 (A_{2}); also elsewhere on the board
I2C_GP3_DAT: TP20.1, U2.5 (A_{1}); also elsewhere on the board
unnamed: D8.A, IC1.3 (LX), IC1.4 (LX), IC1.5 (LX), L1.2
unnamed: C11.2, IC1.10 (OUT), IC1.15 (~3.3/5), IC1.16 (CLK), R40.1
unnamed: IC1.2 (ONA), R35.1
unnamed: C10.1, IC1.8 (REF)
unnamed: C9.2, IC1.7 (SS/LIM)
unnamed: IC1.1 (~{ONB), R34.1
unnamed: R7.1, R8.2, U1.22 (A0)
unnamed: R14.1, U1.2 (SC0)
unnamed: R25.1, U1.4 (SC1)
unnamed: R16.1, U1.6 (SC2)
unnamed: R27.1, U1.8 (SC3)
unnamed: R10.2, U1.19 (SCL)
unnamed: R13.1, U1.1 (SD0)
unnamed: R24.1, U1.3 (SD1)
unnamed: R15.1, U1.5 (SD2)
unnamed: R26.1, U1.7 (SD3)
unnamed: R9.2, U1.20 (SDA)
unnamed: R11.1, U1.24 (~RESET)
VSYNC_CAM0_3V3: D6.5 (CH4), D6.6 (CH4), J6.4, R36.1; also elsewhere on the board
VSYNC_CAM1_3V3: D6.4 (CH3), D6.7 (CH3), J6.5, R37.1; also elsewhere on the board
VSYNC_CAM2_3V3: D6.2 (CH2), D6.9 (CH2), J6.6, R38.1; also elsewhere on the board
VSYNC_CAM3_3V3: D6.1 (CH1), D6.10 (CH1), J6.7, R39.1; also elsewhere on the board

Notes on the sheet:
(3V3 to 5V, 2A)
Can be ommitted if no soft-start is required
I2C address:
0x70h
Liquid lens interface
Triggering with level shift
QWIIC Connector
Step-up DC-DC converter
0b1110000R
I2C Level Shifting
Sync Connector
To camera I2C interfaces
Aux connectors
I2C Multiplexer

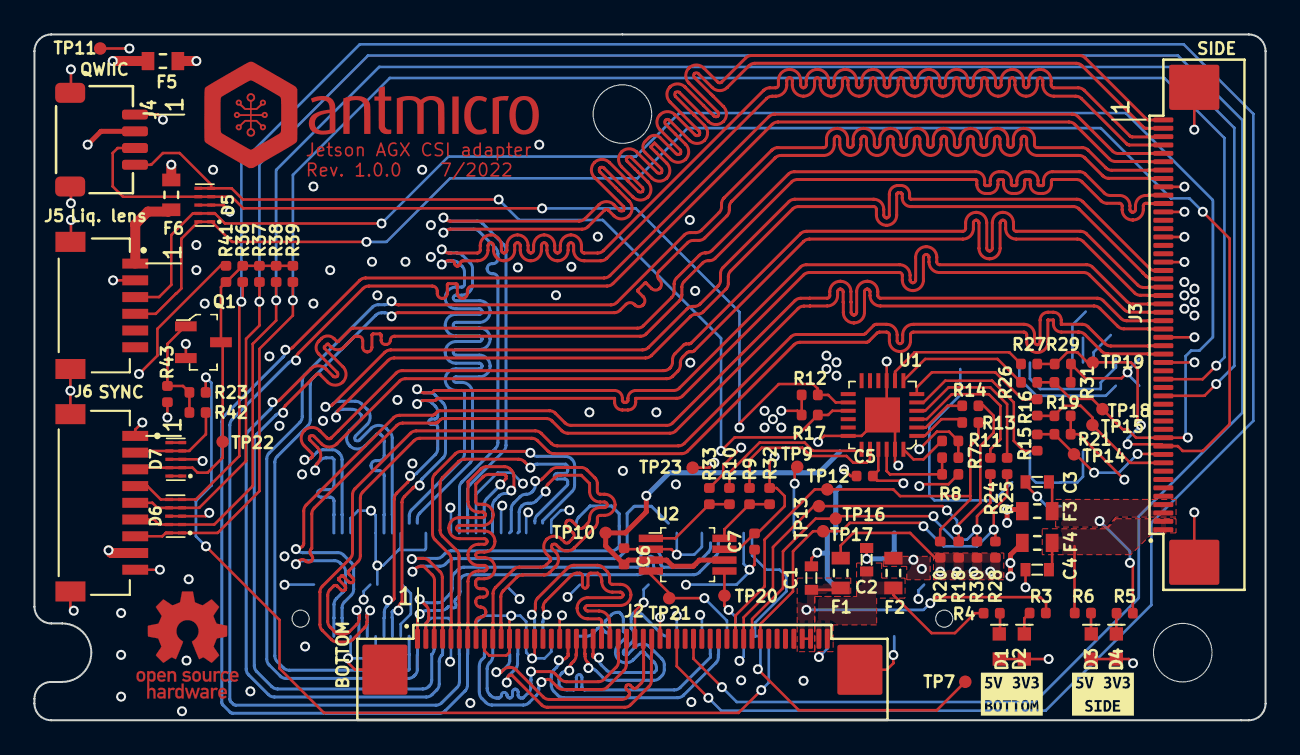
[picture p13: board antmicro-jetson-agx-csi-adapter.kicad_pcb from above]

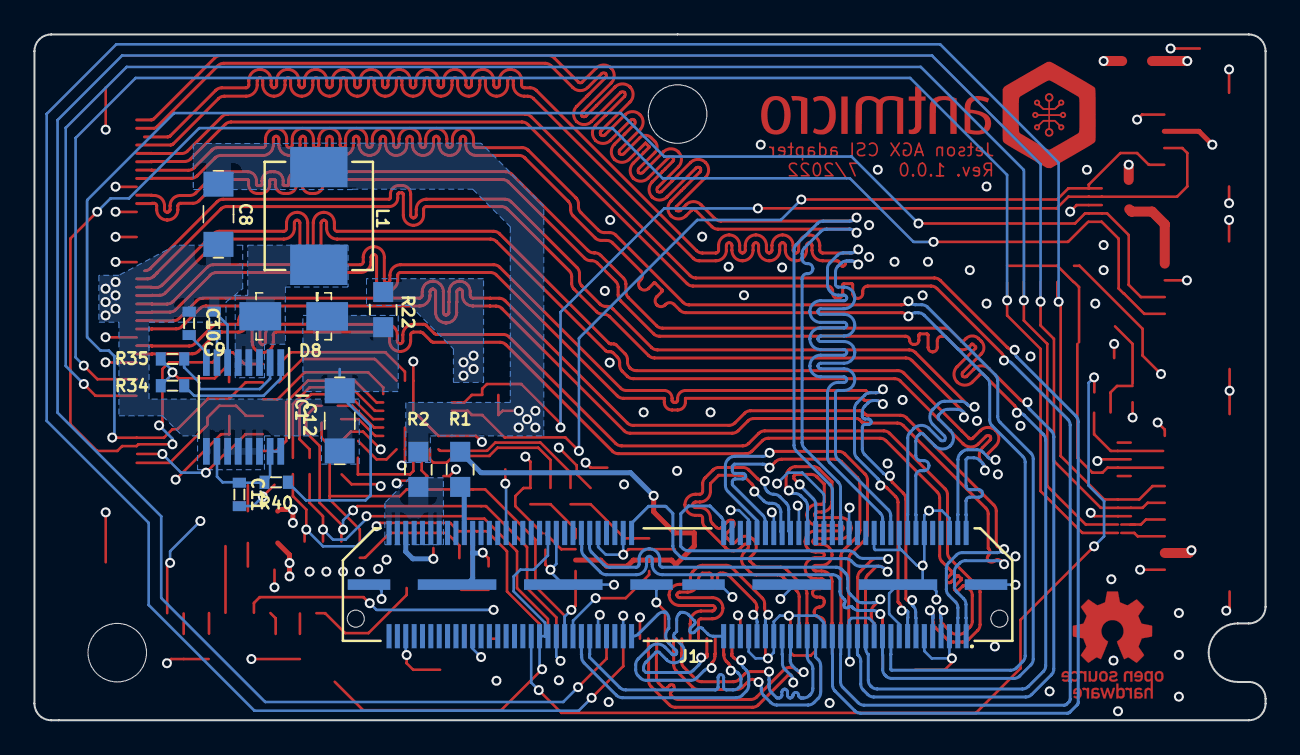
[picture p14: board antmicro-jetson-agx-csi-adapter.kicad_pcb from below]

Board: 4 copper layers, 73.6 x 41.0 mm, 98 parts (15 on the bottom side), 99 nets.

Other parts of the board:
kibuzzard-62DE644D: G***; kibuzzard-62DE644D
kibuzzard-62DE6453: G***; kibuzzard-62DE6453

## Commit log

2022-07-27 Added PCB outline
    [antmicro-jetson-agx-csi-adapter.kicad_pcb]
2022-07-27 Added maximum height of components and fixed connector footprint on mockup pcb
    [antmicro-jetson-agx-csi-adapter.kicad_pcb]
2022-07-27 Fixed adapter types
    [antmicro-jetson-agx-csi-adapter.kicad_sch, cameras.kicad_sch]
2022-07-27 Fixes suggested in review
    [antmicro-jetson-agx-csi-adapter.kicad_sch, cameras.kicad_sch, interface.kicad_sch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]
2022-07-27 Add logos
    [antmicro-jetson-agx-csi-adapter.kicad_sch, cameras.kicad_sch, interface.kicad_sch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]
2022-07-27 Changed pinout to match Jetson Nano Baseboard
    [cameras.kicad_sch]
2022-07-27 Added logos and changed top and bottom side
    [antmicro-jetson-agx-csi-adapter.kicad_pcb]
2022-07-27 Fixed sync pin naming
    [cameras.kicad_sch]
2022-07-27 More changes from review
    [antmicro-jetson-agx-csi-adapter.kicad_sch, auxiliary.kicad_sch, interface.kicad_sch]
2022-07-27 Started PCB layout
    [antmicro-jetson-agx-csi-adapter.kicad_pcb]
2022-07-27 Add TVS to wire connectors
    [antmicro-jetson-agx-csi-adapter.kicad_sch, auxiliary.kicad_sch, interface.kicad_sch]
2022-07-27 Routed CSI interface
    [antmicro-jetson-agx-csi-adapter.kicad_pcb, antmicro-jetson-agx-csi-adapter.kicad_sch, auxiliary.kicad_sch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]
2022-07-27 Routed I2C signals, completed a layout of the voltage converter and I2C IC.
    [antmicro-jetson-agx-csi-adapter.kicad_pcb, antmicro-jetson-agx-csi-adapter.kicad_sch, auxiliary.kicad_sch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]
2022-07-27 Finished layout of most of the other signals, rerouted CSI
    [antmicro-jetson-agx-csi-adapter.kicad_pcb, auxiliary.kicad_sch]
2022-07-27 Replaced some components with larger package, routed more signals
    [antmicro-jetson-agx-csi-adapter.kicad_pcb, antmicro-jetson-agx-csi-adapter.kicad_sch, auxiliary.kicad_sch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]
2022-07-27 Routed all the signals
    [antmicro-jetson-agx-csi-adapter.kicad_pcb]
2022-07-27 Removed AUX connector and changed SYNC connector package
    [antmicro-jetson-agx-csi-adapter.kicad_pcb, antmicro-jetson-agx-csi-adapter.kicad_sch, auxiliary.kicad_sch]
2022-07-27 Rerouted tracks after connector change
    [antmicro-jetson-agx-csi-adapter.kicad_pcb]
2022-07-27 Length matched CSI signals
    [antmicro-jetson-agx-csi-adapter.kicad_pcb, antmicro-jetson-agx-csi-adapter.kicad_sch, auxiliary.kicad_sch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]
2022-07-27 Filleted CSI tracks
    [antmicro-jetson-agx-csi-adapter.kicad_pcb]
2022-07-27 Cleaned up silk screen
    [antmicro-jetson-agx-csi-adapter.kicad_pcb]
2022-07-27 Added fuses for aux connectors
    [antmicro-jetson-agx-csi-adapter.kicad_pcb, antmicro-jetson-agx-csi-adapter.kicad_sch, auxiliary.kicad_sch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]
2022-07-27 Merged zones and minor net fixes
    [antmicro-jetson-agx-csi-adapter.kicad_pcb]
2022-07-27 Swapped QWIIC connector to a side entry one
    [antmicro-jetson-agx-csi-adapter.kicad_pcb, antmicro-jetson-agx-csi-adapter.kicad_sch, auxiliary.kicad_sch]
2022-07-27 Fixed length matching
    [antmicro-jetson-agx-csi-adapter.kicad_pcb]
2022-07-27 Changed 5V converter capacitors to ceramic for lower ESR
    [antmicro-jetson-agx-csi-adapter.kicad_pcb, antmicro-jetson-agx-csi-adapter.kicad_sch, auxiliary.kicad_sch]
2022-07-27 Fixed bottom silkscreen
    [antmicro-jetson-agx-csi-adapter.kicad_pcb, auxiliary.kicad_sch]
2022-07-27 Added loclib, updated README and added pdf schematic
    [antmicro-jetson-agx-csi-adapter.kicad_pcb, antmicro-jetson-agx-csi-adapter.kicad_sch, auxiliary.kicad_sch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]
2022-10-24 Remove redundant sheet
    [peripherals.kicad_sch]
2024-06-14 [#60956] WiP Update symbols references
    [antmicro-jetson-agx-csi-adapter.kicad_pcb, antmicro-jetson-agx-csi-adapter.kicad_sch, auxiliary.kicad_sch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]
2024-06-14 [#60956] WiP Update footprints
    [antmicro-jetson-agx-csi-adapter.kicad_pcb, interface.kicad_sch]
2024-06-18 [#60956] Update B340A-13-F,MAX1708EEE+ and TP_0_75mm from library
    [auxiliary.kicad_sch, interface.kicad_sch]
2024-06-18 [#60956] Allign PCB with SCH changes
    [auxiliary.kicad_sch]
2024-06-18 [#60956] Bump rev to 1.0.1
    [antmicro-jetson-agx-csi-adapter.kicad_sch, auxiliary.kicad_sch, interface.kicad_sch]
2024-06-20 [#60956] Update Max1708 after component rev
    [auxiliary.kicad_sch]
2024-06-24 [#60956] Switch kibuzzard text fields to knockouts
2024-06-24 [#60956] Update dates
    [antmicro-jetson-agx-csi-adapter.kicad_sch, auxiliary.kicad_sch, interface.kicad_sch]
2024-06-26 [#60956] Remove antmicro prefix from board name
2024-06-26 [#60956] Upload stackup.csv
    [stackup.csv]

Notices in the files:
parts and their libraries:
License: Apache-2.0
